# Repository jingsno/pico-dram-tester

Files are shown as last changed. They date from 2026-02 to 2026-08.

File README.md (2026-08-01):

# Pico DRAM Tester

Having trouble with your old-school DIP dynamic RAM chips? Here's a simple
RAM tester that will give you a definitive pass or fail for a variety of
chips.

**New** rev 3 now available! New features include:

* USB-C power connector with PD resistors
* Universal encoder wiring supports Bourns and Panasonic style encoders
* Through-hole footprint for the Pico2 to ease soldering

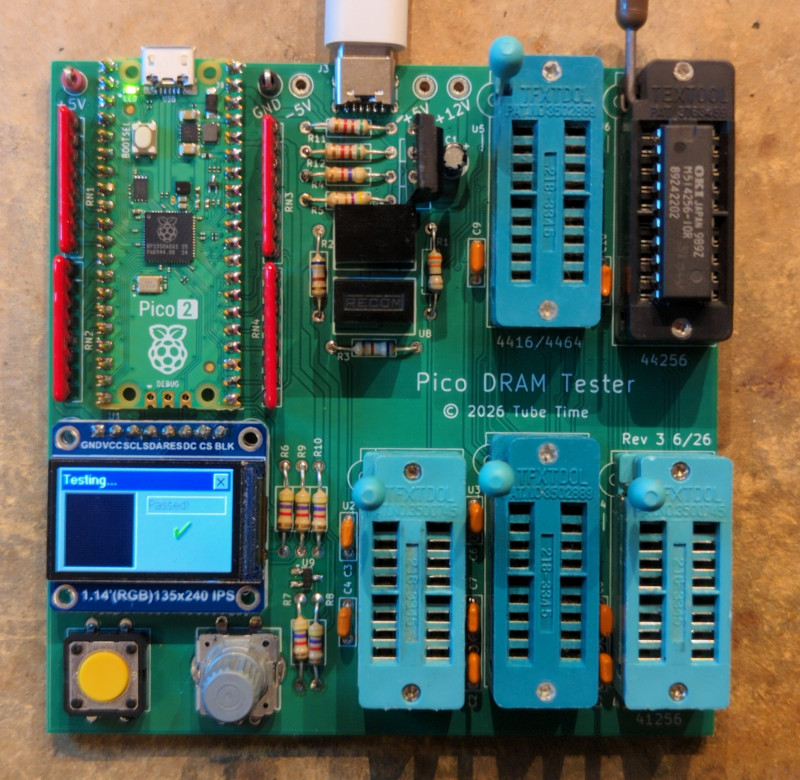
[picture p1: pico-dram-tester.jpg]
Photo of the board


Benefits

* Tests RAM *at full speed* so you can feel confident about a chip that passes.
* Easy to construct with widely-available parts. No surface mount chips.
* Low cost
* Built-in DC-DC modules generate extra voltages required by 4116-class chips
* Can be operated from a bench supply for voltage margin testing

Supported Devices

* 4027 (4K x 1)
* 4108 (8K x 1 that are 4116s with only half test good: MK4108, TMS4108, etc)
* 4116 (16K x 1)
* 4132 (32K x 1, piggyback)
* 4132 (32K x 1 that are 4164s with only half tested good: TMS4532, M3732)
* 4164 (64K x 1)
* 41128 (128K x 1, piggyback)
* 41256 (256K x 1)
* 4416 (16K x 4)
* 4464 (64K x 4)
* 44256 (256K x 4)

Out of scope

* SRAM, DRAM chips larger than 1MBit
* Logic chips

## Construction

[Fab package](fab/pico-dram-tester-rev3.zip)

[Schematic](pico-dram-tester.pdf)

[Bill of Materials](pico-dram-tester.csv)

The board is a simple 2-layer board, 100mm x 100mm, and 1.6mm thick. Fabricate
at your favorite vendor in any color you wish.

You may populate the board only with the sockets for devices you plan to use,
or you may populate all the sockets. You can try substituting the sockets with
standard IC sockets, but I recommend ZIF sockets which are much easier to use.
Why so many sockets? It saves you from having to install dozens of pin control
transistors required to make a tester work with a single universal socket.

If you want to populate the USB-C connector, do it first before any other
components. It makes it much easier to access the surface-mount pins along
the edge with a soldering iron.

Populate Q1, U7, U8, R2, R3, R4, and R5 if you would like to test 4116 and
4132 devices without requiring an external -5V and +12V power supply.

If you want to provide the -5V, +5V, and +12V power from your bench supply,
then you may leave those components off of the board and connect your power
leads to the -5V, +5V, and +12V test points. If you don't plan to test 4116
or 4132 chips, then you can safely leave out those components.

The LCD display is nominally the [Adafruit 4383](https://www.adafruit.com/product/4383) which is to be installed at location J1 (U9 is not required when using
this display). You can also use cheaper devices available from Aliexpress and
others. They are 8-pin LCD displays sold as 1.14" 135x240 IPS ST7789 modules.
Install this display at position J2. You may also need to add the voltage
monitor at position U9.

For several reasons, this board requires a Pico 2 microcontroller board and
will not work at all with the Pico 1.

If you use a Bourns-style encoder, you will need to solder across the jumper
on the back of the board. **This is the most common type of cheaply-available
encoders, so you probably want to do this.** Otherwise, for Panasonic-style
encoders, leave this open.

After installing all the components and inspecting the board for accidental
short circuits, connect the Pico 2 via the USB connector to a computer. The
device should power up and appear as a USB mass storage device. Copy the
prebuilt firmware file [pmemtest.uf2](firmware/pmemtest.uf2) to this device, and the Pico 2 will
program itself. Reset the power and you should see a menu of chips on the LCD
screen.

## Using the DRAM Tester

Before starting, connect the tester to a power source:

* If you did not install U7 and U8, connect a bench supply to the GND, -5V, +5V, and +12V test points. Connect the Pico 2 USB jack to a power adapter or computer.
* If you installed U7 and U8, connect a 5V bench supply to the 5VIN and GND test points. Instead of a bench supply, you could connect the Pico 2 USB jack to a power adapter, but you won't be able to control the voltage. A computer often has a much lower voltage and you may fail RAM chips that actually function at 5V.

1. Install the chip in the socket designated for that type of memory chip, following the pin 1 orientation (the pin 1 notch faces the ZIF socket lever). Note that some of the sockets are used for several types of memory.
2. Rotate the selection knob until the correct part number is highlighted, and push down on the top of the selection knob (it's also a button!)
3. If you make a mistake, press the button to the left of the selection knob to go back.
4. After selecting a part, you need to pick the correct speed grade to run the
test. Often the speed grade is marked on the chip as a suffix. For example, -15
typically means 150ns. If you're not sure, pick the slowest speed.
5. If you are using an external bench power supply to supply -5V and +12V, turn it on now. If you soldered in the on-board voltage converter modules, you don't need to do anything. Push the top of the selection knob to continue.
6. The test runs. You will see a red "X" if the test fails or a green checkmark if the test passes.
7. You can rerun the test immediately by pushing down on the top of the selection knob. Or go back to the menu by pushing the button to the left.

Note: The visualization pane on the left is just for entertainment and doesn't
really represent bad bits.

## Technical Details

The Pico 2 microcontroller (RP2350) has built-in high-speed PIO processors
which are overclocked to 300MHz. This means that the DRAM timing can be set
to a resolution of 3.3ns. The RAM test runs on the second CPU core, decoupling
it from the GUI, which runs on the first CPU core.

RAM testing can be surprisingly complicated. There are many kinds of failures:

* Stuck-at fault - a cell is stuck at a 1 or a 0
* Stuck-open fault - a cell isn't connected (input or output)
* Transition fault - a cell can't go from one state to another (1 to 0 or 0 to 1)
* Data retention fault - a cell flips after a time delay
* Coupling fault - the state of one cell affects the state of another
* Neighborhood pattern sensitive fault - a specific pattern in nearby cells causes a cell to flip
* Address decoder fault - cells may be isolated, or multiple cells accessed at the same address, or multiple addresses may access a single cell

There are a number of "traditional" RAM tests such as the checkerboard or
walking 1/0, but these tests can be slow and don't have precise coverage over
all failure modes. The Pico DRAM Tester uses more modern testing algorithms:

* March-B. This is a sequence of linear reads and writes designed to catch address faults, stuck-at faults, transition faults, and coupling faults.
* Pseudorandom test. This test loads a pseudorandom number sequence into the memory, reads it back, and checks to make sure it didn't change. The test is repeated with 64 different pseudorandom patterns to enhance coverage. The patterns are identical between runs, making the test repeatable. The test only uses pseudorandom data and does not randomize the address. This test can detect many pattern-sensitive faults.
* Refresh test. This test loads a pattern into the memory, waits for a time delay, and then tries to read it back. The time delay is longer than a typical refresh rate. This test can detect data retention faults.

## Known Issues

* The 41128 test is not yet reliable.

## Troubleshooting

Check your solder connections. Does the Pico 2 board show up in bootloader mode when you plug it into a computer?

The Pico DRAM Tester uses an overclocked Pico 2 configuration.
Some Pico 2 boards may not work well at 300MHz, crashing or not drawing the GUI on the screen correctly.
You may be able to get it working by editing pmemtest.c, find the line `vreg_set_voltage(VREG_VOLTAGE_1_15);` and change the voltage setting to `VREG_VOLTAGE_1_20`.

## License

This work is licensed under a Creative Commons Attribution-ShareAlike 4.0
International License. See [https://creativecommons.org/licenses/by-sa/4.0/](https://creativecommons.org/licenses/by-sa/4.0/).

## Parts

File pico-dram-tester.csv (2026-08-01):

Qty | Reference | Value | DNP | Mouser
1 | C1 | 10uF |  | 667-ECA-1VM100
9 | C2,C3,C4,C5,C6,C7,C8,C9,C10 | 0.1uF |  | 80-C322C104M5U
1 | J1 | TFT 4383
1 | J2 | mrd_114_ips_lcd_8p
1 | J3 | POWER |  | 179-UJCHGSMT1P6TR
1 | JP1 | TYPE
1 | Q1 | SUP53P06-20-E3 or equiv |  | 781-SUP53P06-20-E3
1 | R1 | 33 |  | 594-MBB02070C3309FCT
2 | R2,R3 | 680 |  | 594-MBB02070C6800FCT
6 | R4,R6,R7,R8,R9,R10 | 4.7K |  | 594-MBB02070C4701FCT
1 | R5 | 100 |  | 594-MBB02070C1000FCT
2 | R11,R12 | 5.1K |  | 594-MBB02070C5101FCT
4 | RN1,RN2,RN3,RN4 | 33 |  | 652-4608X-2LF-33
1 | SW1 | RotaryEncoder_Switch
1 | SW2 | BACK |  | 653-B3F-4005
1 | TP1 | 5V |  | 534-5005
1 | TP2 | GND |  | 534-5006
1 | TP3 | 12V |  | 534-5009
1 | TP4 | -5V |  | 534-5007
1 | TP5 | 5VIN |  | 534-5005
1 | U1 | PICO2 |  | 358-SC1631
1 | U2 | 4116
1 | U3 | 4132
1 | U4 | 4164/41128/41256
1 | U5 | 4416/4464
1 | U6 | 44256
1 | U7 | DCDC_ITR03 |  | 490-ITR0305S12
1 | U8 | RFM-0505S |  | 919-RFM-0505S
1 | U9 | APX803S |  | 621-APX803S-29SA-7

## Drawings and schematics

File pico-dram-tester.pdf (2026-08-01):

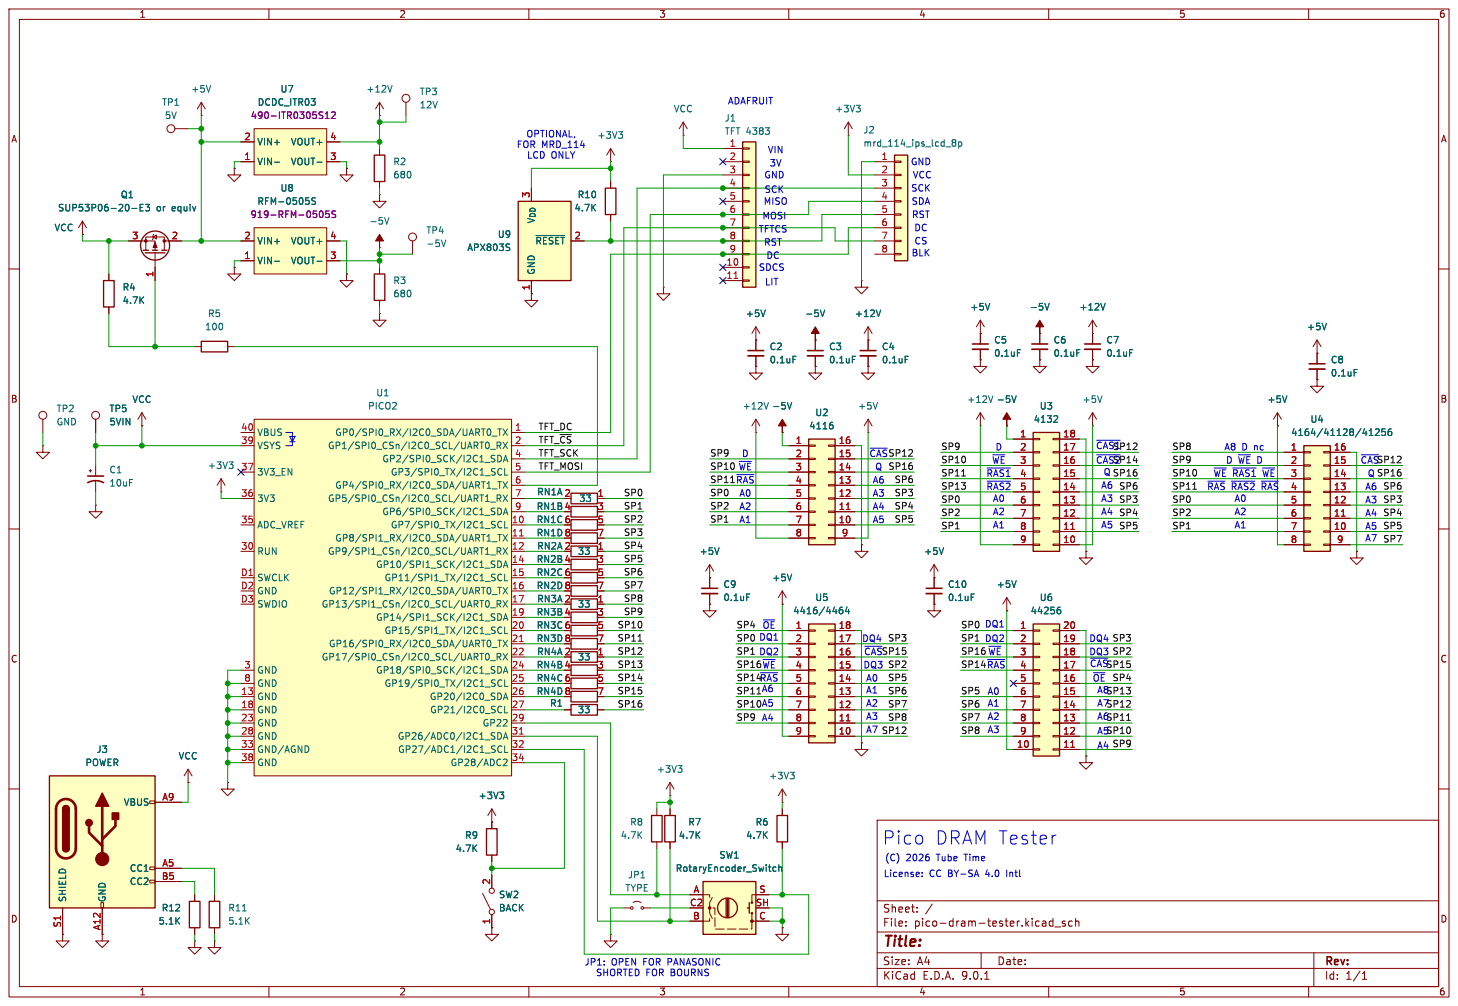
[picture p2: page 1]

Id: 1/1 Title: File: pico-dram-tester.kicad_sch Sheet: /

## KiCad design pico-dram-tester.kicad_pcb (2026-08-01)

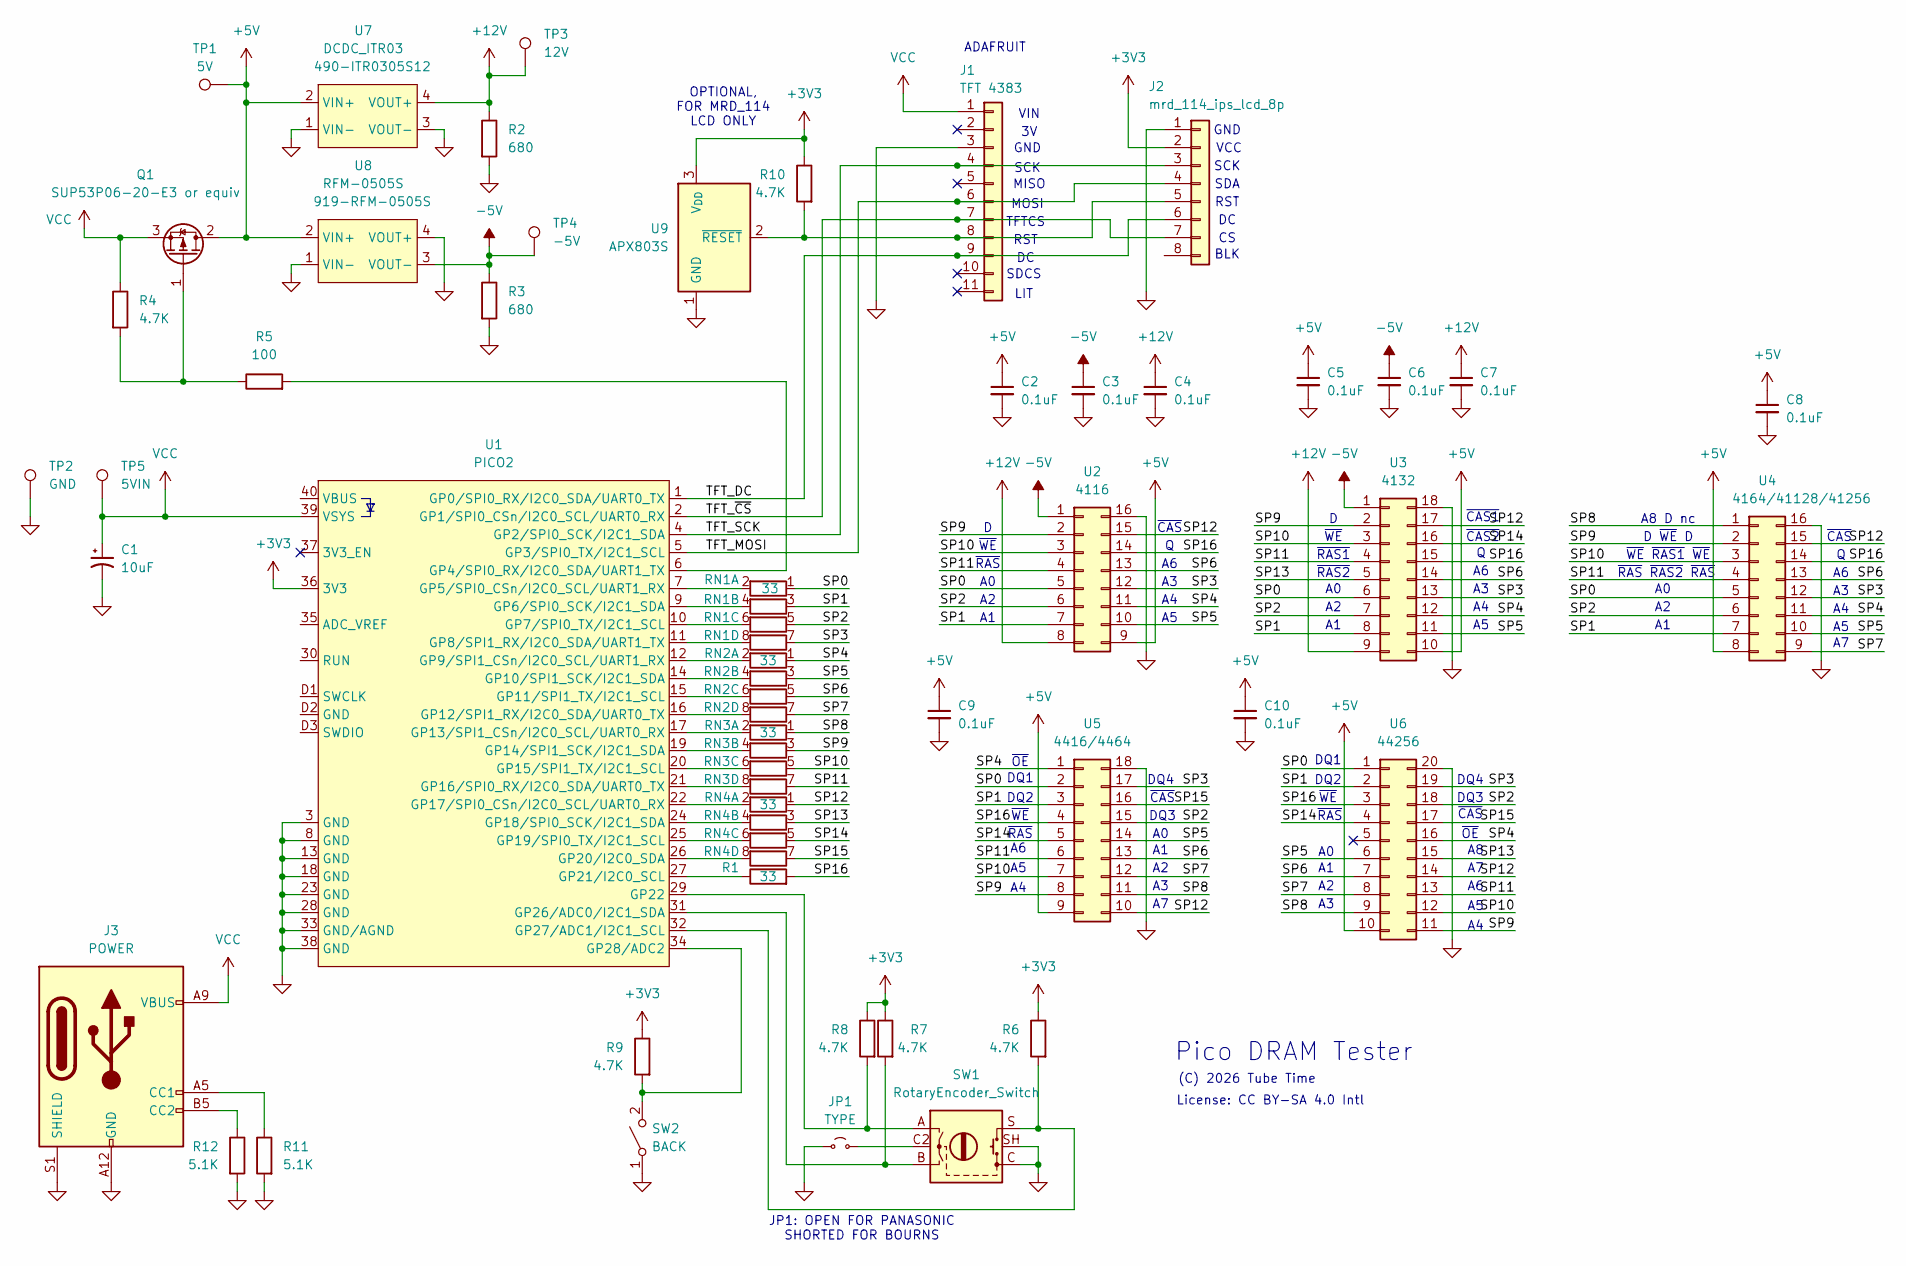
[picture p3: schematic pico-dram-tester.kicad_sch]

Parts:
C1: 10uF; CAPAE200P500X1100; Mouser 667-ECA-1VM100
C2, C3, C4, C5, C6, C7, C8, C9, C10: 0.1uF; CAPAC200; Mouser 80-C322C104M5U
J1: TFT 4383; ADAFRUIT_4383
J2: mrd_114_ips_lcd_8p; PinHeader_1x08_P2.54mm_Vertical
J3: POWER; USB_C_Receptacle_GCT_USB4125-xx-x-0190_6P_TopMnt_Horizontal; Mouser 179-UJCHGSMT1P6TR
JP1: TYPE; SolderJumper-2_P1.3mm_Open_Pad1.0x1.5mm
Q1: SUP53P06-20-E3 or equiv; TO-220-3_Vertical; Mouser 781-SUP53P06-20-E3
R1: 33; RESA500; Mouser 594-MBB02070C3309FCT
R2, R3: 680; RESA500; Mouser 594-MBB02070C6800FCT
R4, R6, R7, R8, R9, R10: 4.7K; RESA500; Mouser 594-MBB02070C4701FCT
R5: 100; RESA500; Mouser 594-MBB02070C1000FCT
R11, R12: 5.1K; RESA500; Mouser 594-MBB02070C5101FCT
RN1, RN2, RN3, RN4: 33; R_Array_SIP8; Mouser 652-4608X-2LF-33
SW1: RotaryEncoder_Switch; ENCODER_SW_UNIV
SW2: BACK; SW_SPST_Omron_B3F-50xx; Mouser 653-B3F-4005
TP1: 5V; TestPoint_Keystone_5005-5009_Compact; Mouser 534-5005
TP2: GND; TestPoint_Keystone_5005-5009_Compact; Mouser 534-5006
TP3: 12V; TestPoint_Keystone_5005-5009_Compact; Mouser 534-5009
TP4: -5V; TestPoint_Keystone_5005-5009_Compact; Mouser 534-5007
TP5: 5VIN; TestPoint_Keystone_5005-5009_Compact; Mouser 534-5005
U1: PICO2; Pico2_PTH; Mouser 358-SC1631
U2: 4116; DIP_Socket-16_W4.3_W5.08_W7.62_W10.16_W10.9_3M_216-3340-00-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
U3: 4132; DIP_Socket-18_W4.3_W5.08_W7.62_W10.16_W10.9_3M_218-3341-00-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
U4: 4164/41128/41256; DIP_Socket-16_W4.3_W5.08_W7.62_W10.16_W10.9_3M_216-3340-00-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
U5: 4416/4464; DIP_Socket-18_W4.3_W5.08_W7.62_W10.16_W10.9_3M_218-3341-00-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
U6: 44256; DIP_Socket-20_W4.3_W5.08_W7.62_W10.16_W10.9_3M_220-3342-00-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
U7: DCDC_ITR03; Mouser 490-ITR0305S12
U8: RFM-0505S; DCDC_ITR03; Mouser 919-RFM-0505S
U9: APX803S; SOT-23_Handsoldering; Mouser 621-APX803S-29SA-7

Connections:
+3V3: J2.2, R6.1, R7.1, R8.1, R9.1, R10.1, U1.36 (3V3), U9.3 (V_{DD})
+5V: C2.1, C5.1, C8.1, C9.1, C10.1, Q1.2 (D), TP1.1, U2.9, U3.10, U4.8, U5.9, U6.10, U7.2 (VIN+), U8.2 (VIN+)
+12V: C4.1, C7.1, R2.1, TP3.1, U2.8, U3.9, U7.4 (VOUT+)
-5V: C3.1, C6.1, R3.1, TP4.1, U2.1, U3.1, U8.3 (VOUT-)
/SP0: RN1.1 (R1.1), U2.5, U3.6, U4.5, U5.2, U6.1
/SP1: RN1.3 (R2.1), U2.7, U3.8, U4.7, U5.3, U6.2
/SP2: RN1.5 (R3.1), U2.6, U3.7, U4.6, U5.15, U6.18
/SP3: RN1.7 (R4.1), U2.12, U3.13, U4.12, U5.17, U6.19
/SP4: RN2.1 (R1.1), U2.11, U3.12, U4.11, U5.1, U6.16
/SP5: RN2.3 (R2.1), U2.10, U3.11, U4.10, U5.14, U6.6
/SP6: RN2.5 (R3.1), U2.13, U3.14, U4.13, U5.13, U6.7
/SP7: RN2.7 (R4.1), U4.9, U5.12, U6.8
/SP8: RN3.1 (R1.1), U4.1, U5.11, U6.9
/SP9: RN3.3 (R2.1), U2.2, U3.2, U4.2, U5.8, U6.11
/SP10: RN3.5 (R3.1), U2.3, U3.3, U4.3, U5.7, U6.12
/SP11: RN3.7 (R4.1), U2.4, U3.4, U4.4, U5.6, U6.13
/SP12: RN4.1 (R1.1), U2.15, U3.17, U4.15, U5.10, U6.14
/SP13: RN4.3 (R2.1), U3.5, U6.15
/SP14: RN4.5 (R3.1), U3.16, U5.5, U6.4
/SP15: RN4.7 (R4.1), U5.16, U6.17
/SP16: R1.2, U2.14, U3.15, U4.14, U5.4, U6.3
/TFT_DC: J1.9, J2.6, U1.1 (GP0/SPI0_RX/I2C0_SDA/UART0_TX)
/TFT_MOSI: J1.6, J2.4, U1.5 (GP3/SPI0_TX/I2C1_SCL)
/TFT_SCK: J1.4, J2.3, U1.4 (GP2/SPI0_SCK/I2C1_SDA)
/TFT_~CS: J1.7, J2.7, U1.2 (GP1/SPI0_CSn/I2C0_SCL/UART0_RX)
GND: C1.2, C2.2, C3.2, C4.2, C5.2, C6.2, C7.2, C8.2, C9.2, C10.2, J1.3, J2.1, J3.A12 (GND), J3.B12 (GND), J3.S1 (SHIELD), JP1.1 (A), R2.2, R3.2, R11.2, R12.2, SW1.C, SW1.SH, SW2.1 (A), TP2.1, U1.3 (GND), U1.8 (GND), U1.13 (GND), U1.18 (GND), U1.23 (GND), U1.28 (GND), U1.33 (GND/AGND), U1.38 (GND), U2.16, U3.18, U4.16, U5.18, U6.20, U7.1 (VIN-), U7.3 (VOUT-), U8.1 (VIN-), U8.4 (VOUT+), U9.1 (GND)
unnamed: J1.8, J2.5, R10.2, U9.2 (~RESET)
unnamed: J3.A5 (CC1), R11.1
unnamed: J3.B5 (CC2), R12.1
unnamed: JP1.2 (B), SW1.C2 (C)
unnamed: Q1.1 (G), R4.2, R5.1
unnamed: RN1.2 (R1.2), U1.7 (GP5/SPI0_CSn/I2C0_SCL/UART1_RX)
unnamed: RN1.4 (R2.2), U1.9 (GP6/SPI0_SCK/I2C1_SDA)
unnamed: RN1.6 (R3.2), U1.10 (GP7/SPI0_TX/I2C1_SCL)
unnamed: RN1.8 (R4.2), U1.11 (GP8/SPI1_RX/I2C0_SDA/UART1_TX)
unnamed: RN2.2 (R1.2), U1.12 (GP9/SPI1_CSn/I2C0_SCL/UART1_RX)
unnamed: RN2.4 (R2.2), U1.14 (GP10/SPI1_SCK/I2C1_SDA)
unnamed: RN2.6 (R3.2), U1.15 (GP11/SPI1_TX/I2C1_SCL)
unnamed: RN2.8 (R4.2), U1.16 (GP12/SPI1_RX/I2C0_SDA/UART0_TX)
unnamed: RN3.2 (R1.2), U1.17 (GP13/SPI1_CSn/I2C0_SCL/UART0_RX)
unnamed: RN3.4 (R2.2), U1.19 (GP14/SPI1_SCK/I2C1_SDA)
unnamed: RN3.6 (R3.2), U1.20 (GP15/SPI1_TX/I2C1_SCL)
unnamed: RN3.8 (R4.2), U1.21 (GP16/SPI0_RX/I2C0_SDA/UART0_TX)
unnamed: RN4.2 (R1.2), U1.22 (GP17/SPI0_CSn/I2C0_SCL/UART0_RX)
unnamed: RN4.4 (R2.2), U1.24 (GP18/SPI0_SCK/I2C1_SDA)
unnamed: RN4.6 (R3.2), U1.25 (GP19/SPI0_TX/I2C1_SCL)
unnamed: RN4.8 (R4.2), U1.26 (GP20/I2C0_SDA)
unnamed: R9.2, SW2.2 (B), U1.34 (GP28/ADC2)
unnamed: R5.2, U1.6 (GP4/SPI0_RX/I2C0_SDA/UART1_TX)
unnamed: R1.1, U1.27 (GP21/I2C0_SCL)
unnamed: R8.2, SW1.A, U1.29 (GP22)
unnamed: R7.2, SW1.B, U1.31 (GP26/ADC0/I2C1_SDA)
unnamed: R6.2, SW1.S, U1.32 (GP27/ADC1/I2C1_SCL)
VCC: C1.1, J1.1, J3.A9 (VBUS), J3.B9 (VBUS), Q1.3 (S), R4.1, TP5.1, U1.39 (VSYS)

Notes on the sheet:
~{OE}
~{CAS}
~{RAS}
ADAFRUIT
GND
BLK
LIT
~{WE}
~{CAS2}
~{CAS1}
License: CC BY-SA 4.0 Intl
MOSI
DQ2
SDCS
(C) 2026 Tube Time
DQ3
~{RAS} ~{RAS2} ~{RAS}
OPTIONAL, FOR MRD_114 LCD ONLY
A8 D nc
DQ1
TFTCS
JP1: OPEN FOR PANASONIC SHORTED FOR BOURNS
DQ4
SCK
~{RAS1}
~{RAS2}
VIN
SDA
VCC
Pico DRAM Tester
D ~{WE} D
~{WE} ~{RAS1} ~{WE}
RST
MISO

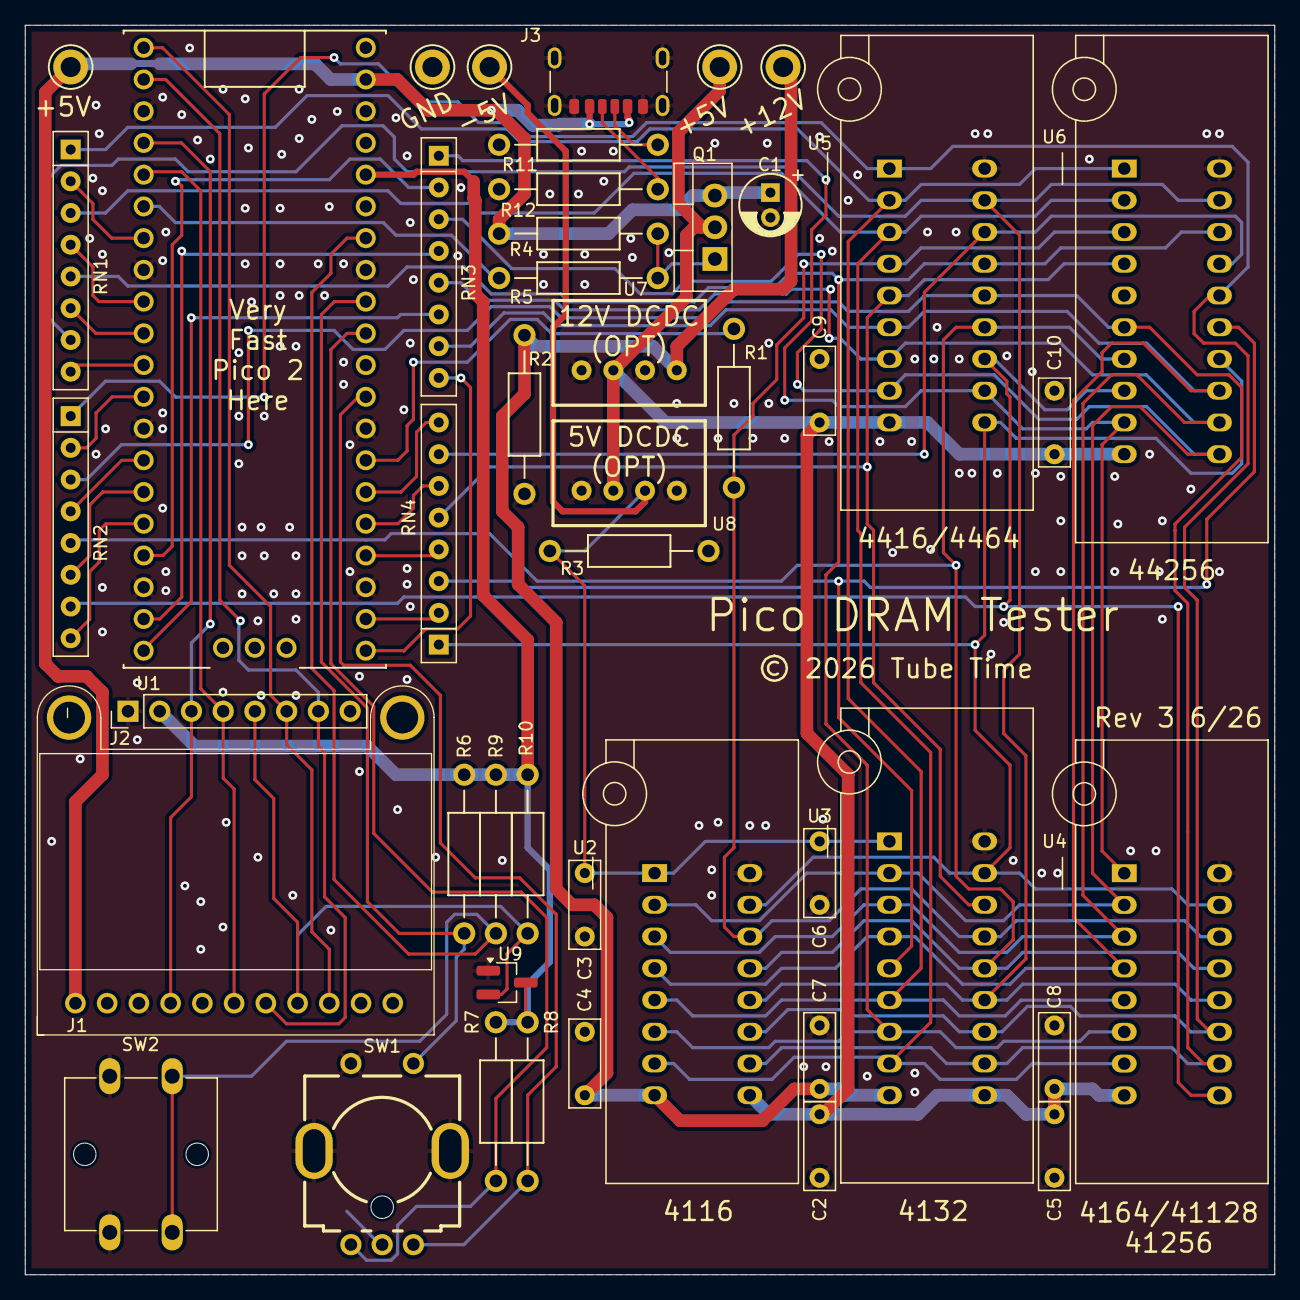
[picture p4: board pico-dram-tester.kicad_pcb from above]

Board: 2 copper layers, 100.0 x 100.0 mm, 47 parts (1 on the bottom side), 54 nets.

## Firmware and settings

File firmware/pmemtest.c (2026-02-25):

// Main entry point

// TODO:
// Make the refresh test fancier
// Bug fix the 41128

#include <stdio.h>
#include <stdint.h>
#include "pico/stdlib.h"
#include "pico/multicore.h"
#include "pico/util/queue.h"
#include "hardware/pio.h"
#include "hardware/vreg.h"
#include "hardware/clocks.h"
#include "pio_patcher.h"
#include "mem_chip.h"
#include "xoroshiro64starstar.h"

PIO pio;
uint sm = 0;
uint offset; // Returns offset of starting instruction

// Defined RAM pio programs
#include "ram4116.pio.h"
#include "ram4132.pio.h"
#include "ram4164.pio.h"
#include "ram41128.pio.h"
#include "ram41256.pio.h"
#include "ram_4bit.pio.h"

#include "st7789.h"

// Icons
#include "chip_icon.h"
#include "warn_icon.h"
#include "error_icon.h"
#include "check_icon.h"
#include "drum_icon0.h"
#include "drum_icon1.h"
#include "drum_icon2.h"
#include "drum_icon3.h"

#include "gui.h"


#define GPIO_POWER 4
#define GPIO_QUAD_A 22
#define GPIO_QUAD_B 26
#define GPIO_QUAD_BTN 27
#define GPIO_BACK_BTN 28
#define GPIO_LED 25

// Status shared variables between cores
// Not really thread safe but this
// status is unimportant.
volatile int stat_cur_addr;
volatile int stat_old_addr;
volatile int stat_cur_bit;
queue_t stat_cur_test;
volatile int stat_cur_subtest;

static uint ram_bit_mask;

gui_listbox_t *cur_menu;

#define MAIN_MENU_ITEMS 16
char *main_menu_items[MAIN_MENU_ITEMS];
gui_listbox_t main_menu = {7, 40, 220, MAIN_MENU_ITEMS, 4, 0, 0, main_menu_items};

#define NUM_CHIPS 12
const mem_chip_t *chip_list[] = {&ram4027_chip, &ram4116_half_chip, &ram4116_chip,
                                 &ram4132_stk_chip, &ram4164_half_chip, &ram4164_chip,
                                 &ram41128_chip, &ram41256_chip, &ram4416_half_chip,
                                 &ram4416_chip, &ram4464_chip, &ram44256_chip};

gui_listbox_t variants_menu = {7, 40, 220, 0, 4, 0, 0, 0};
gui_listbox_t speed_menu = {7, 40, 220, 0, 4, 0, 0, 0};


typedef enum {
    MAIN_MENU,
    VARIANT_MENU,
    SPEED_MENU,
    DO_SOCKET,
    DO_TEST,
    TEST_RESULTS
} gui_state_t;

gui_state_t gui_state = MAIN_MENU;

void setup_main_menu()
{
    uint i;
    for (i = 0; i < NUM_CHIPS; i++) {
        main_menu_items[i] = (char *)chip_list[i]->chip_name;
    }
    main_menu.tot_lines = NUM_CHIPS;
}

// Function queue entry for dispatching worker functions
typedef struct
{
    uint32_t (*func)(uint32_t, uint32_t);
    uint32_t data;
    uint32_t data2;
} queue_entry_t;

queue_t call_queue;
queue_t results_queue;

// Entry point for second core. This is just a generic
// function dispatcher lifted from the Raspberry Pi example code.
void core1_entry() {
    while (1) {
        // Function pointer is passed to us via the queue_entry_t which also
        // contains the function parameter.
        // We provide an int32_t return value by simply pushing it back on the
        // return queue which also indicates the result is ready.

        queue_entry_t entry;

        queue_remove_blocking(&call_queue, &entry);

        int32_t result = entry.func(entry.data, entry.data2);

        queue_add_blocking(&results_queue, &result);
    }
}

// Routines for turning on-board power on and off
static inline void power_on()
{
    gpio_set_dir(GPIO_POWER, true);
    gpio_put(GPIO_POWER, false);
    sleep_ms(100);
}

static inline void power_off()
{
    gpio_set_dir(GPIO_POWER, false);
}

// Wrapper that just calls the read routine for the selected chip
static inline int ram_read(int addr)
{
    return chip_list[main_menu.sel_line]->ram_read(addr);
}

// Wrapper that just calls the write routine for the selected chip
static inline void ram_write(int addr, int data)
{
    chip_list[main_menu.sel_line]->ram_write(addr, data);
}

// Low level routines for march-b algorithm
static inline bool me_r0(int a)
{
    int bit = ram_read(a) & ram_bit_mask;
    return (bit == 0);
}

static inline bool me_r1(int a)
{
    int bit = ram_read(a) & ram_bit_mask;
    return (bit == ram_bit_mask);
}

static inline bool me_w0(int a)
{
    ram_write(a, ~ram_bit_mask);
    return true;
}

static inline bool me_w1(int a)
{
    ram_write(a, ram_bit_mask);
    return true;
}

static inline bool marchb_m0(int a)
{
    me_w0(a);
    return true;
}

static inline bool marchb_m1(int a)
{
    return me_r0(a) && me_w1(a) && me_r1(a) && me_w0(a) && me_r0(a) && me_w1(a);
}

static inline bool marchb_m2(int a)
{
    return me_r1(a) && me_w0(a) && me_w1(a);
}

static inline bool marchb_m3(int a)
{
    return me_r1(a) && me_w0(a) && me_w1(a) && me_w0(a);
}

static inline bool marchb_m4(int a)
{
    return me_r0(a) && me_w1(a) && me_w0(a);
}

static inline bool march_element(int addr_size, bool descending, int algorithm)
{
    int inc = descending ? -1 : 1;
    int start = descending ? (addr_size - 1) : 0;
    int end = descending ? -1 : addr_size;
    int a;
    bool ret;

    stat_cur_subtest = algorithm;

    for (stat_cur_addr = start; stat_cur_addr != end; stat_cur_addr += inc) {
        switch (algorithm) {
            case 0:
                ret = marchb_m0(stat_cur_addr);
                break;
            case 1:
                ret = marchb_m1(stat_cur_addr);
                break;
            case 2:
                ret = marchb_m2(stat_cur_addr);
                break;
            case 3:
                ret = marchb_m3(stat_cur_addr);
                break;
            case 4:
                ret = marchb_m4(stat_cur_addr);
                break;
            default:
                break;
        }
        if (!ret) return false;
    }
    return true;
}

uint32_t marchb_testbit(uint32_t addr_size)
{
    bool ret;
    ret = march_element(addr_size, false, 0);
    if (!ret) return false;
    ret = march_element(addr_size, false, 1);
    if (!ret) return false;
    ret = march_element(addr_size, false, 2);
    if (!ret) return false;
    ret = march_element(addr_size, true, 3);
    if (!ret) return false;
    ret = march_element(addr_size, true, 4);
    if (!ret) return false;
    return true;
}

// Runs the memory test on the 2nd core
uint32_t marchb_test(uint32_t addr_size, uint32_t bits)
{
    int failed = 0;
    int bit = 0;

    for (bit = 0; bit < bits; bit++) {
        stat_cur_bit = bit;
        ram_bit_mask = 1 << bit;
        if (!marchb_testbit(addr_size)) {
            failed |= 1 << bit; // fail flag
        }
    }

    return (uint32_t)failed;
}

#define PSEUDO_VALUES 64
#define ARTISANAL_NUMBER 42
static uint64_t random_seeds[PSEUDO_VALUES];

void psrand_init_seeds()
{
    int i;
    psrand_seed(ARTISANAL_NUMBER);
    for (i = 0; i < PSEUDO_VALUES; i++) {
        random_seeds[i] = psrand_next();
    }
}

uint32_t psrand_next_bits(uint32_t bits)
{
    static int bitcount = 0;
    static uint32_t cur_rand;
    uint32_t out;

    if (bitcount < bits) {
        cur_rand = psrand_next();
        bitcount = 32;
    }

    out = cur_rand & ((1 << (bits)) - 1);
    cur_rand = cur_rand >> bits;
    bitcount -= bits;
    return out;
}


// Pseudorandom test
uint32_t psrandom_test(uint32_t addr_size, uint32_t bits)
{
    uint i;
    uint32_t bitsout;
    uint32_t bitsin;
    uint32_t bitshift = addr_size / 4;

    // Write seeded pseudorandom data
    for (i = 0; i < PSEUDO_VALUES; i++) {
        stat_cur_subtest = i >> 2;
        stat_cur_bit = i & 3;
        psrand_seed(random_seeds[i]);
        for (stat_cur_addr = 0; stat_cur_addr < addr_size; stat_cur_addr++) {
            bitsout = psrand_next_bits(bits);
            ram_write(stat_cur_addr, bitsout);
        }

        // Reseed and then read the data back
        psrand_seed(random_seeds[i]);
        for (stat_cur_addr = 0; stat_cur_addr < addr_size; stat_cur_addr++) {
            bitsout = psrand_next_bits(bits);
            bitsin = ram_read(stat_cur_addr);
            if (bitsout != bitsin) {
                return 1;
            }
        }
    }

    return 0;
}

uint32_t refresh_subtest(uint32_t addr_size, uint32_t bits, uint32_t time_delay)
{
    uint32_t bitsout;
    uint32_t bitsin;

    psrand_seed(random_seeds[0]);
    for (stat_cur_addr = 0; stat_cur_addr < addr_size; stat_cur_addr++) {
        bitsout = psrand_next_bits(bits);
        ram_write(stat_cur_addr, bits);
    }

    sleep_us(time_delay);

    psrand_seed(random_seeds[0]);
    for (stat_cur_addr = 0; stat_cur_addr < addr_size; stat_cur_addr++) {
        bitsout = psrand_next_bits(bits);
        bitsin = ram_read(stat_cur_addr);
        if (bits != bitsin) {
            return 1;
        }
    }
    return 0;
}


uint32_t refresh_test(uint32_t addr_size, uint32_t bits)
{
    return refresh_subtest(addr_size, bits, 5000);
}


static const char *ram_test_names[] = {"March-B", "Pseudo", "Refresh"};

// Initial entry for the RAM test routines running
// on the second CPU core.
uint32_t all_ram_tests(uint32_t addr_size, uint32_t bits)
{
    int failed;
    int test = 0;
// Initialize RAM by performing n RAS cycles
    march_element(addr_size, false, 0);
// Now run actual tests
    queue_add_blocking(&stat_cur_test, &test);
    failed = marchb_test(addr_size, bits);
    if (failed) return failed;
    test = 1;
    queue_add_blocking(&stat_cur_test, &test);
    failed = psrandom_test(addr_size, bits);
    if (failed) return failed;
    test = 2;
    queue_add_blocking(&stat_cur_test, &test);
    failed = refresh_test(addr_size, bits);
    if (failed) return failed;
    return 0;
}

typedef struct {
    uint32_t pin;
    uint32_t hcount;
} pin_debounce_t;

#define ENC_DEBOUNCE_COUNT 1000
#define BUTTON_DEBOUNCE_COUNT 50000

// Debounces a pin
uint8_t do_debounce(pin_debounce_t *d)
{
    if (gpio_get(d->pin)) {
        d->hcount++;
        if (d->hcount > ENC_DEBOUNCE_COUNT) d->hcount = ENC_DEBOUNCE_COUNT;
    } else {
        d->hcount = 0;
    }
    return (d->hcount >= ENC_DEBOUNCE_COUNT) ? 1 : 0;
}

// Returns true only *once* when a button is pushed. No key repeat.
bool is_button_pushed(pin_debounce_t *pin_b)
{
    if (!gpio_get(pin_b->pin)) {
        if (pin_b->hcount == 0) {
            pin_b->hcount = BUTTON_DEBOUNCE_COUNT;
            return true;
        }
    } else {
        if (pin_b->hcount > 0) {
            pin_b->hcount--;
        }
    }
    return false;
}

// Setup and display the main menu
void show_main_menu()
{
    cur_menu = &main_menu;
    paint_dialog("Select Device");
    gui_listbox(cur_menu, LIST_ACTION_NONE);
}

void show_variant_menu()
{
    uint chip = main_menu.sel_line;
    cur_menu = &variants_menu;
    paint_dialog("Select Variant");
    variants_menu.items = (char **)chip_list[chip]->variants->variant_names;
    variants_menu.tot_lines = chip_list[chip]->variants->num_variants;
    gui_listbox(cur_menu, LIST_ACTION_NONE);
}

// With the selected chip, populate the speed grade menu and show it
void show_speed_menu()
{
    uint chip = main_menu.sel_line;
    cur_menu = &speed_menu;
    paint_dialog("Select Speed Grade");
    speed_menu.items = (char **)chip_list[chip]->speed_names;
    speed_menu.tot_lines = chip_list[chip]->speed_grades;
    gui_listbox(cur_menu, LIST_ACTION_NONE);
}


#define CELL_STAT_X 9
#define CELL_STAT_Y 33

// Used to update the RAM test GUI left pane
static inline void update_vis_dot(uint16_t cx, uint16_t cy, uint16_t col)
{
    st7789_fill(CELL_STAT_X + cx * 3, CELL_STAT_Y + cy * 3, 2, 2, col);
}

#define STATUS_ICON_X 155
#define STATUS_ICON_Y 65

struct repeating_timer drum_timer;

// Play the drums
bool drum_animation_cb(__unused struct repeating_timer *t)
{
    static uint8_t drum_st = 0;
    drum_st++;
    if (drum_st > 3) drum_st = 0;
    st7789_fill(STATUS_ICON_X, STATUS_ICON_Y, 32, 32, COLOR_LTGRAY);
    switch (drum_st) {
        case 0:
            draw_icon(STATUS_ICON_X, STATUS_ICON_Y, &drum_icon0);
            break;
        case 1:
            draw_icon(STATUS_ICON_X, STATUS_ICON_Y, &drum_icon1);
            break;
        case 2:
            draw_icon(STATUS_ICON_X, STATUS_ICON_Y, &drum_icon2);
            break;
        case 3:
            draw_icon(STATUS_ICON_X, STATUS_ICON_Y, &drum_icon3);
            break;
    }
    return true;
}

// Show the RAM test console GUI
void show_test_gui()
{
    uint16_t cx, cy;
    paint_dialog("Testing...");

    // Cell status area. 32x32 elements.
    fancy_rect(7, 31, 100, 100, B_SUNKEN_OUTER); // Usable size is 220x80.
    fancy_rect(8, 32, 98, 98, B_SUNKEN_INNER);
    st7789_fill(9, 33, 96, 96, COLOR_BLACK);
    for (cy = 0; cy < 32; cy++) {
        for (cx = 0; cx < 32; cx++) {
            update_vis_dot(cx, cy, COLOR_DKGRAY);
        }
    }
    stat_old_addr = 0;
    stat_cur_bit = 0;
    stat_cur_subtest = 0;

    // Current test indicator
    paint_status(120, 35, 110, "      ");
    draw_icon(STATUS_ICON_X, STATUS_ICON_Y, &drum_icon0);
    add_repeating_timer_ms(-100, drum_animation_cb, NULL, &drum_timer);
}

// Begins the RAM test with the selected RAM chip
void start_the_ram_test()
{
    // Get the power turned on
    power_on();

    // Get the PIO going
    chip_list[main_menu.sel_line]->setup_pio(speed_menu.sel_line, variants_menu.sel_line);

    // Dispatch the second core
    // (The memory size is from our memory description data structure)
    queue_entry_t entry = {all_ram_tests,
                           chip_list[main_menu.sel_line]->mem_size,
                           chip_list[main_menu.sel_line]->bits};
    queue_add_blocking(&call_queue, &entry);
}

// Stops the RAM test
void stop_the_ram_test()
{
    chip_list[main_menu.sel_line]->teardown_pio();
    power_off();
}

// Figure out where visualization dot goes and map it
static inline void map_vis_dot(int addr, int ox, int oy, int bitsize, uint16_t col)
{
    int cx, cy;
    if (bitsize == 4) {
        cx = addr & 0xf;
        cy = (addr >> 4) & 0xf;
    } else {
        cx = addr & 0x1f;
        cy = (addr >> 5) & 0x1f;
    }
    update_vis_dot(cx + ox, cy + oy, col);
}

// Draw up visualization from current test state
void do_visualization()
{
    const uint16_t cmap[] = {COLOR_DKBLUE, COLOR_DKGREEN, COLOR_DKMAGENTA, COLOR_DKYELLOW, COLOR_GREEN};
    int bitsize = chip_list[main_menu.sel_line]->bits;
    int new_addr = stat_cur_addr * 1024 / chip_list[main_menu.sel_line]->mem_size / bitsize;
    int bit = stat_cur_bit;
    uint16_t col = cmap[stat_cur_subtest];
    int delta, i;
    int ox, oy = 0;

    if (bitsize == 4) {
        switch (bit) {
            case 1:
                oy = 0;
                ox = 16;
                break;
            case 2:
                oy = 16;
                ox = 0;
                break;
            case 3:
                ox = oy = 16;
                break;
            default:
                ox = oy = 0;
        }
    } else {
        ox = oy = 0;
    }

    if (new_addr > stat_old_addr) {
        delta = new_addr - stat_old_addr;
        for (i = 0; i < delta; i++) {
            map_vis_dot(stat_old_addr + i, ox, oy, bitsize, col);
        }
    } else {
        delta = stat_old_addr - new_addr;
        for (i = delta - 1; i >= 0; i--) {
            map_vis_dot(stat_old_addr + i, ox, oy, bitsize, col);
        }
    }
    stat_old_addr = new_addr;
}

// During a RAM test, updates the status window and checks for the end of the test
void do_status()
{
    uint32_t retval;
    char retstring[30];
    uint16_t v;
    static uint16_t v_prev = 0;
    int test;

    if (gui_state == DO_TEST) {
        do_visualization();

        // Update the status text
        if (queue_try_remove(&stat_cur_test, &test)) {
            paint_status(120, 35, 110, "      ");
            paint_status(120, 35, 110, (char *)ram_test_names[test]);
        }

        // Check official status
        if (!queue_is_empty(&results_queue)) {
            stop_the_ram_test();
            // The RAM test completed, so let's handle that
            sleep_ms(10);
            // No more drums
            cancel_repeating_timer(&drum_timer);
            queue_remove_blocking(&results_queue, &retval);
            // Show the completion status
            gui_state = TEST_RESULTS;
            st7789_fill(STATUS_ICON_X, STATUS_ICON_Y, 32, 32, COLOR_LTGRAY); // Erase icon
            if (retval == 0) {
                paint_status(120, 35, 110, "Passed!");
                draw_icon(STATUS_ICON_X, STATUS_ICON_Y, &check_icon);
            } else {
                draw_icon(STATUS_ICON_X, STATUS_ICON_Y, &error_icon);
                if (chip_list[main_menu.sel_line]->bits == 4) {
                    sprintf(retstring, "Failed %d%d%d%d", (retval >> 3) & 1,
                                                           (retval >> 2) & 1,
                                                            (retval >> 1) & 1,
                                                            (retval & 1));
                    paint_status(120, 105, 110, retstring);
                } else {
                    paint_status(120, 105, 110, "Failed");
                }
            }
        }
    }
}

// Called when user presses the action button
void button_action()
{
    // Do something based on the current menu
    switch (gui_state) {
        case MAIN_MENU:
            // Check for variant
            if (chip_list[main_menu.sel_line]->variants == NULL) {
                gui_state = SPEED_MENU;
                show_speed_menu();
            } else {
                gui_state = VARIANT_MENU;
                show_variant_menu();
            }
            break;
        case VARIANT_MENU:
            // Set up variant
            gui_state = SPEED_MENU;
            show_speed_menu();
            break;
        case SPEED_MENU:
            gui_messagebox("Place Chip in Socket",
                           "Turn on external supply afterwards, if used.", &chip_icon);
            gui_state = DO_SOCKET;
            break;
        case DO_SOCKET:
            gui_state = DO_TEST;
            show_test_gui();
            start_the_ram_test();
            break;
        case DO_TEST:
            break;
        case TEST_RESULTS:
            // Quick retest to save time
            gui_state = DO_TEST;
            show_test_gui();
            start_the_ram_test();
            break;
        default:
            gui_state = MAIN_MENU;
            break;
    }
}

// Called when the user presses the back button
void button_back()
{
    switch (gui_state) {
        case MAIN_MENU:
            break;
        case VARIANT_MENU:
            gui_state = MAIN_MENU;
            show_main_menu();
            break;
        case SPEED_MENU:
            // Check if our selection has a variant
            if (chip_list[main_menu.sel_line]->variants == NULL) {
                gui_state = MAIN_MENU;
                show_main_menu();
            } else {
                gui_state = VARIANT_MENU;
                show_variant_menu();
            }
            break;
        case DO_SOCKET:
            gui_state = SPEED_MENU;
            show_speed_menu();
            break;
        case DO_TEST:
            break;
        case TEST_RESULTS:
            gui_state = SPEED_MENU;
            show_speed_menu();
            break;
        default:
            gui_state = MAIN_MENU;
            break;
    }
}

void do_buttons()
{
    static pin_debounce_t action_btn = {GPIO_QUAD_BTN, 0};
    static pin_debounce_t back_btn = {GPIO_BACK_BTN, 0};
    if (is_button_pushed(&action_btn)) button_action();
    if (is_button_pushed(&back_btn)) button_back();
}

void wheel_increment()
{
    if (gui_state == MAIN_MENU || gui_state == SPEED_MENU || gui_state == VARIANT_MENU) {
        gui_listbox(cur_menu, LIST_ACTION_DOWN);
    }
}

void wheel_decrement()
{
    if (gui_state == MAIN_MENU || gui_state == SPEED_MENU || gui_state == VARIANT_MENU) {
        gui_listbox(cur_menu, LIST_ACTION_UP);
    }
}
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
int main() {
    uint offset;
    uint16_t addr;
    uint8_t db = 0;
    uint din = 0;
    int i, retval;

    // Increase core voltage slightly (default is 1.1V) to better handle overclock
    vreg_set_voltage(VREG_VOLTAGE_1_20);
    sleep_ms(50);

    // Overclock to 300 Mhz
    set_sys_clock_pll(1500000000, 5, 1);

    // PLL->prim = 0x51000.

    //stdio_uart_init_full(uart0, 57600, 28, 29); // 28=tx, 29=rx actually runs at 115200 due to overclock
    //gpio_init(15);
    //gpio_set_dir(15, GPIO_OUT);

    //printf("Test.\n");
    psrand_init_seeds();

    gpio_init(GPIO_LED);
    gpio_set_dir(GPIO_LED, GPIO_OUT);
    gpio_put(GPIO_LED, 1);

    gpio_init(GPIO_POWER);
    power_off();

    // Set up second core
    queue_init(&call_queue, sizeof(queue_entry_t), 2);
    queue_init(&results_queue, sizeof(int32_t), 2);
    queue_init(&stat_cur_test, sizeof(int), 2);

    // Second core will wait for the call queue.
    multicore_launch_core1(core1_entry);

    // Init display
    st7789_init();

    setup_main_menu();
 //   gui_demo();
    show_main_menu();
    init_buttons_encoder();


// Testing
#if 0
    power_on();
    ram44256_setup_pio(5);
    sleep_ms(10);
    for (i=0; i < 100; i++) {
        ram44256_ram_read(i&7);
        ram44256_ram_write(i&7, 1);
        ram44256_ram_read(i&7);
        ram44256_ram_write(i&7, 0);
//gpio_put(GPIO_LED, marchb_test(8, 1));
    }
    while(1) {}
#endif

    while(1) {
        do_encoder();
        do_buttons();
        do_status();
    }

    while(1) {
//        printf("Begin march test.\n");
        retval = marchb_test(65536, 1);
//        printf("Rv: %d\n", retval);
    }

    return 0;
}

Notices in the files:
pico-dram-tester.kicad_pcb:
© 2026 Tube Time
